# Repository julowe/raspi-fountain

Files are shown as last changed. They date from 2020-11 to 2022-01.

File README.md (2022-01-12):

# Raspberry Pi Fountain Style Case
Case for Raspberry Pi/RetroPi in shape of a fountain basin.

This repo contains an OpenSCAD file for the basin (with base) that I created. It currently includes friction fit posts for statues and raspi.

Repo also includes two STL file I did not create - [gargoyles](https://www.thingiverse.com/thing:2490820) and [a central column](https://www.thingiverse.com/thing:2179993). Remember to scale up the central column...

Inspiration from [this fountain on Thingiverse](https://www.thingiverse.com/thing:2144984).

## Printing

Printed at 0.12mm layer height mostly on Ender 3 with Marble PLA, to fair success.

Just did lazy way of creating 5.2mm cube voids (in slicing program) in bottom of gargoyle and column models so they would fit on friction fit posts on basin. In hindsight, just using the 5mm diameter heatset inserts and having holes in the basin top (vs somewhat fragile posts) would have been better.

## Assembly
All heatset insert void were made for 5mm diameter m3 versions. Along with holes and screw-head insets on bottom of base. Roughly need:

* 3 M3 12mm for base
* 1 M3 16mm? for base (or you know, fix the basin model so you don't have to hack away plastic to get power cord to fit)
* 1 M3 5mm for pi corner retainer (ideally would be a M2.5 and associated heatset insert, but lacking them and the will, I filed the mounting hole on the pi larger)
* 4 M3 12mm for fan

Pi currently oriented with power and hdmi cables coming out smaller hole, USB cables coming out of larger hole.

Fan red wire attached to 3V (vs 5V) for quieter running. Pins bent out and labeled on base, but look up RasPi pinout for 3V and ground to see where to attach.

Pictures follow:

Assembled Fountain

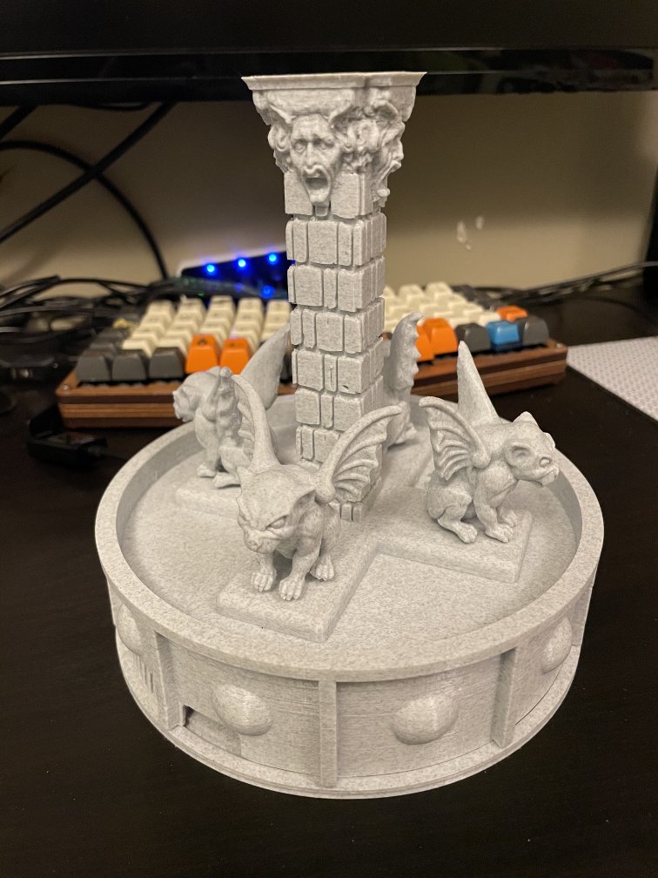
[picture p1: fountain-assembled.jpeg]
Fountain


Inside of fountain, showing orientation of Pi

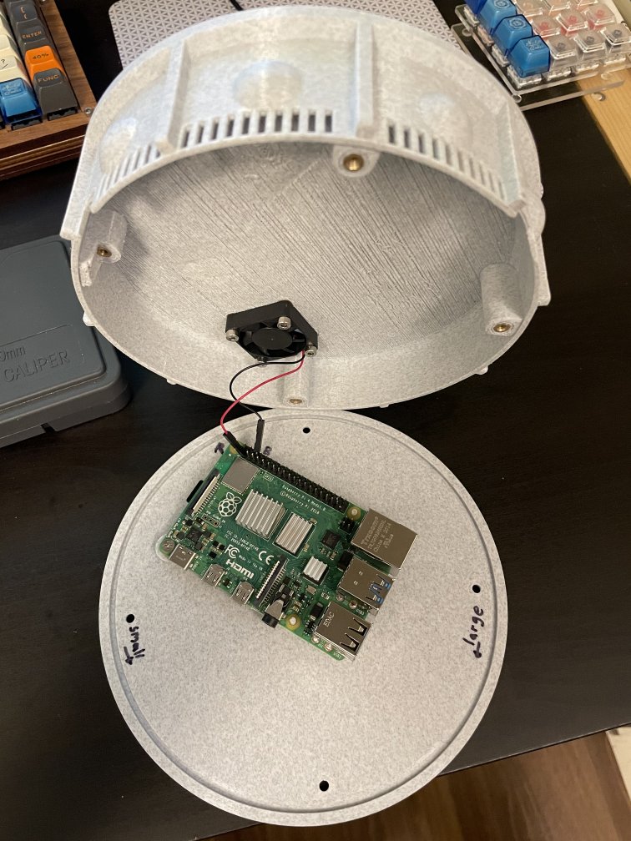
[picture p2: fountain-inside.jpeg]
Inside of Fountain Basin


Basin top showing friction fit posts and attachment point on gargoyle model

Showing friction fit posts and gargoyle attachment spot

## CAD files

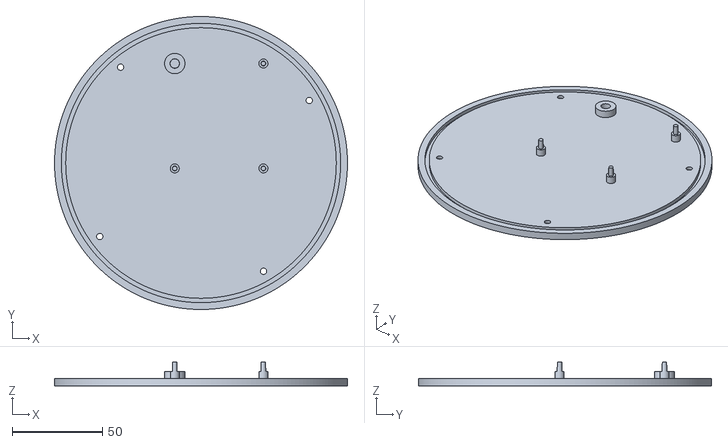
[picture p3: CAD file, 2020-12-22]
fountain-base.stl
162.0 x 162.0 x 13.0

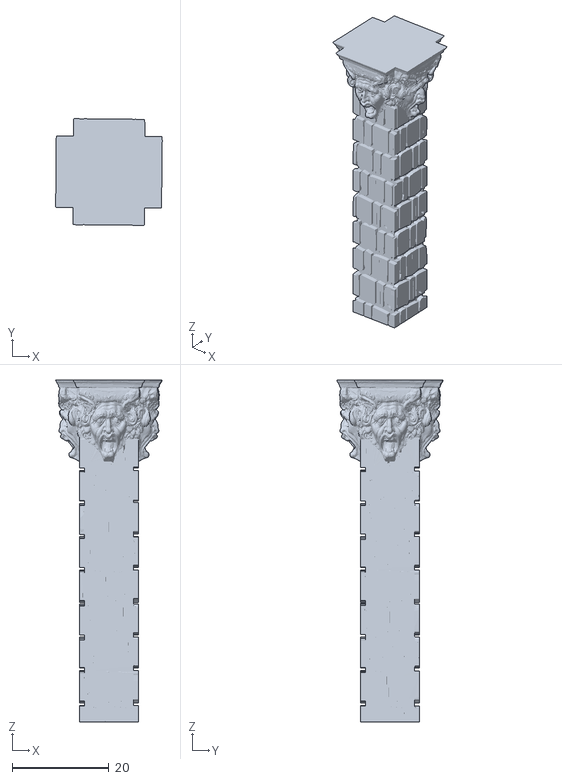
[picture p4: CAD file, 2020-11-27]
Gargoyle_Fountain-spout_tall.stl
22.1 x 22.1 x 70.8

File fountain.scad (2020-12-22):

//Fountain & RetroPi Case
//justin Lowe 20201123

//outline:
//make island for imported models
//import gargoyle x4 (52mm wide 39mm deep, 50mm tall)
//import spout/coumn (22mm square, 70.8mm tall)
//make basin
//make base

//fan 30mm square, 7mm deep
//pi is 90mm, 58mm, 21mm high]


//maybe TODO
//more/bigger fan vents?
//make vents travel up to top of basin further?
//fan cable clip behind holder


draftingFNs = 36;
renderFNs = 180;
$fn = draftingFNs;


//////////////////////////////////////////////////

printHorizontalTolerance = 0.1;

islandRadius = 53;

gutterRadius = 75-islandRadius;
gutterHeight = 15;

wallMinThickness = 2;
wallUprightsThickness = 4;
wallHeight = 45;
wallInsetRingDepth = 2; //how deep of a trench to make in the base, for the basin to sit in?
wallInsetRingGap = 1; //how much shorter should the basin wall be, then the trench that it goes into?
wallInsetTolerance = 0.2; //how much bigger to make trench than the basin wall that goes into it - applied to RADIUS, so this much gap is on inside an doutside of trench compared to basin wall remember

//not needed :-(
wholeRadius = (wallUprightsThickness+wallMinThickness+gutterRadius+islandRadius);
wholeCircumf = wholeRadius*2*PI;
partsCircum = wholeCircumf/(wallHeight-wallUprightsThickness*2);
echo(floor(wholeRadius));

baseHeight = wallUprightsThickness;
mountingPegHeight = 5;
mountingPegRadius = 2.7/2;
mountingPegBaseHeight = 4;
mountingPegBaseRadius = 5/2;
fanHolderWallThickness = 2;
fanThickness = 7.8;
fanWidth = 30.5;
fanCornerWidth = 6;

//58mm between center long side moutning holes
//49mm between center short side moutning holes
//2.7mm inner diam mounting hole
//6mm outerdiam mounting hole copper
//3.5mm mounting hole center is away from edge of board (with microsd holder)
//9mm center usb1 from edge of board
//27mm center usb2 from edge of board
//so, 18mm diff, so 9mm + 9mm=18mm is center between usb1 & 2
//board 56mm wide, 85mm long



//heat insert mounts
voidInsertRadius = 5.3/2;
voidInsertHeight = 5;
voidInsertHeightBottomPadding = 2;
voidInsertWallThickness = 3;

// [+x/+y, -x/+y, ... 
//TODO fix/test new alignment of -x/+y heat inset - it is too close to power cable from pi
//is 120 good? was 130.
heatSetHoleRotationMatrix = [30,120,216,300];

rotHeat = 9; //how many degrees to rotate heat insert on basin walls to center them
gapBaseBasinFactor = 1.05; //factor to multiple base height by to get a small gap between heat set insert and actual base plate - not used.
gapBaseBasinSize = 0.24; //absolute size to add to get a small gap between heat set insert and actual base plate - about one printed layer




gargoyleOffset = -45;
columnScaling = 1.8;
statueHeight = wallHeight-5;



module frictionFitPosts(){
//column friction fit post
translate([0,0,5/2+statueHeight]){
    cube([5,5,5],true);
}
//gargoyle friction fit post
translate([0,gargoyleOffset+10,5/2+statueHeight]){
    cube([5,5,5],true);
}

//gargoyle friction fit post
rotate([0,0,90]){
    translate([0,gargoyleOffset+10,5/2+statueHeight]){
        cube([5,5,5],true);
    }
}
//gargoyle friction fit post
rotate([0,0,180]){
    translate([0,gargoyleOffset+10,5/2+statueHeight]){
        cube([5,5,5],true);
    }
}
//gargoyle friction fit post
rotate([0,0,-90]){
    translate([0,gargoyleOffset+10,5/2+statueHeight]){
        cube([5,5,5],true);
    }
}
}
//whitespace



module showStatues(){
    
//tall central column
rotate([0,0,0]){
    translate([0,0,statueHeight]){
        scale([columnScaling,columnScaling,columnScaling]){
            translate([-24.32,-28.92,0]){
                import("/home/justin/code/raspi-fountain/Gargoyle_Fountain-spout_tall.stl");
            }
        }
    }
}

////original height central column
//rotate([0,0,0]){
//    translate([0,0,statueHeight]){
//        scale([columnScaling,columnScaling,columnScaling]){
//            translate([-24.32,-28.92,0]){
//                import("/home/justin/code/raspi-fountain/Gargoyle_Fountain-spout.stl");
//            }
//        }
//    }
//}

translate([0,gargoyleOffset,statueHeight]){
    import("/home/justin/code/raspi-fountain/Gargoyle.stl");
}

rotate([0,0,90]){
    translate([0,gargoyleOffset,statueHeight]){
    import("/home/justin/code/raspi-fountain/Gargoyle.stl");
    }
}

rotate([0,0,180]){
    translate([0,gargoyleOffset,statueHeight]){
    import("/home/justin/code/raspi-fountain/Gargoyle.stl");
    }
}

rotate([0,0,-90]){
    translate([0,gargoyleOffset,statueHeight]){
    import("/home/justin/code/raspi-fountain/Gargoyle.stl");
    }
}


    //
    //translate([24.32,28.92,5/2]){
    //    color("Red")
    ////    cube([22.1,22.1,70.8],true); //true size
    //    cube([5,5,5],true); //true size
    //  }

}
//whitespace


islandWidth = 28;
islandLength = (abs(gargoyleOffset)+12)*2;
piClearance = 16+2+4+2; //16 for usb, 2 for board, 4 for friction fit peg bases, 2 for some for slack
//piClearance = fanWidth;
islandCircleHeight = 6; //heatset inserts are 5mm deep
islandCircleZ = piClearance + baseHeight;
minkRadPlinth = 3;
minkRadVoid = 5;

module island(){
difference(){
    union(){ 
        //main circular platform to support plinths
        translate([0,0,islandCircleZ-minkRadVoid]){
            color("Blue")
            cylinder(islandCircleHeight+minkRadVoid, gutterRadius+islandRadius, gutterRadius+islandRadius); 
        }
    
        //island plinth cube
        color("LightBlue")
        minkowski(){
            translate([0,0,statueHeight/2]){
                cube([islandLength,islandWidth,statueHeight],true);
            }
            translate([0,0,0-minkRadPlinth]){
                sphere(minkRadPlinth);
            }
        }
        
        //island plinth cube
        color("LightBlue")
        minkowski(){
            translate([0,0,statueHeight/2]){
                cube([islandWidth,islandLength,statueHeight],true);
            }
            translate([0,0,0-minkRadPlinth]){
                sphere(minkRadPlinth);
            }
        }
    }//end union
    
    minkFudgeHeight = 2; //subtraction void is just barely under islandCircleZ, so adding extra height
    //subtraction cylinder to create void for fan vent  
    translate([33,33,islandCircleZ-minkFudgeHeight/2]){
        color("Green")
        cylinder(islandCircleHeight+minkFudgeHeight, 14, 14);
    }
    
    heatSetInsertHoleOffsetFanHolder = (30/2)-3;
    //subtraction cylinder for heatset insert to hold fan  
    for (i = [-1:2:1]) {
        for (j = [-1:2:1]) {
            translate([33+(i*heatSetInsertHoleOffsetFanHolder),33+(j*heatSetInsertHoleOffsetFanHolder),islandCircleZ-minkFudgeHeight]){
                color("Green")
                //magic number to not go through island but tradeoff with having some gap for melt
                cylinder(voidInsertHeight+0.5+minkFudgeHeight, voidInsertRadius, voidInsertRadius);
            }
        }
    }
    
    //remove bottom of plints and chamfer bottom edge of island
    minkowski(){
        translate([0,0,-minkRadVoid]){
            cylinder(islandCircleZ,gutterRadius+islandRadius-minkRadVoid,gutterRadius+islandRadius-minkRadVoid);
        }
        translate([0,0,0]){
            sphere(minkRadVoid);
        }
    }
} //end difference

//28.25 inner diameter fan ring
//29.8 length swaure of fan
//2 width of fan central bars, so use 3

//fan outflow vent supports/struts
translate([33,33,islandCircleZ]){
    color("DarkSlateGray")
    cylinder(islandCircleHeight, 17.5/2, 17.5/2);
}
translate([33,33,islandCircleZ]){
    rotate([0,0,180]){
        translate([0,-3/2,0]){
            cube([15,3,islandCircleHeight]);
        }
    }
    rotate([0,0,180+120]){
        translate([0,-3/2,0]){
            cube([15,3,islandCircleHeight]);
        }
    }
    rotate([0,0,180+240]){
        translate([0,-4/2,0]){
            cube([15,4,islandCircleHeight]);
        }
    }
} //end fan vent struts

}
//whitespace
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

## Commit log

2020-11-27 Initial commit and close to first draft model
    [Gargoyle_Fountain-spout_tall.stl, fountain.scad]
2020-11-27 changing some measurements, cleanup
    [fountain.scad]
2020-11-27 island changes
    [fountain.scad]
2020-11-27 option to rotate center column
    [fountain.scad]
2020-11-27 add ridge under top lip, so no supports needed for printing
    [fountain.scad]
2020-11-27 move hemispherical bosses down bc new top ridge
    [fountain.scad]
2020-11-27 sub fan vent for intake vents
    [fountain.scad]
2020-11-27 cable passthroughs
    [fountain.scad]
2020-11-27 corrected names for mounting holes, move fan mount
    [fountain.scad]
2020-11-27 remove outer wall stand-in for test print
    [fountain.scad]
2020-11-28 TODOs and ideas added
    [fountain.scad]
2020-11-29 draft fan holder (under island)
    [fountain.scad]
2020-12-01 small tester for fan width with supports
    [fan-tester.scad]
2020-12-05 passthroughs now smaller and have cutout bottom
    [fountain.scad]
2020-12-05 more fan vents next to power passthrough
    [fountain.scad]
2020-12-05 basin now made to sit in base
    [fountain.scad]
2020-12-05 base now has trench for basin wall
    [fountain.scad]
2020-12-05 comment out fan holder on base
    [fountain.scad]
2020-12-05 cleanup comments & whitespace
    [fountain.scad]
2020-12-11 chamfer bottom edge of island cylinder and small code refactor
    [fountain.scad]
2020-12-11 remove some old unused now fan holder code
    [fountain.scad]
2020-12-11 heat insert testing and comment cleanup
    [fountain.scad]
2020-12-11 better minkowski variable names
    [fountain.scad]
2020-12-11 heatset inserts on basin wall
    [fountain.scad]
2020-12-11 screw holes in base using for-loop
    [fountain.scad]
2020-12-11 add heatset holders for fan. comment cleanup
    [fountain.scad]
2020-12-16 comment cleanup
    [fountain.scad]
2020-12-16 update real world measurements
    [fountain.scad]
2020-12-16 update heatset insert structures on basin wall. remove to do's that were done
    [fountain.scad]
2020-12-22 add TODO of fixing hetset insert rotation, code cleanup
    [fountain.scad]
2020-12-22 Updated readme for assembly, add STLs of fountain basin & base
    [fountain-base.stl]
2020-12-22 remove file, different fan mount used
    [fan-tester.scad]
